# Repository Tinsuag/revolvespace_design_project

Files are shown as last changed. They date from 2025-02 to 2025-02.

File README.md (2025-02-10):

# revolvespace_design_project

## 📡 Introduction

Welcome to the GitHub repository for the **CubeSat SARA solar tracking and Torque Measurement Testing Jig**. This project focuses on the conceptual and functional design of a specialized testing jig developed to measure the torque output of the stepper motor-driven mechanism in SARA, a CubeSat subsystem designed to optimize solar energy intake through precise sun-tracking capabilities.

The testing jig is engineered based on **Advanced Mechanical Design Methods**, ensuring accurate, repeatable, and reliable performance validation. The system simulates real-world load conditions encountered in space while eliminating environmental interferences like temperature fluctuations and gravitational effects.

## 🔑 Key Features
- **🗜️ Modular Rotational Base:** Adaptable to various CubeSat models for versatile testing.
- **⚙️ Torque Measurement System:** Utilizes strain gauges in a Wheatstone bridge configuration, connected to a differential amplifier for precise torque readings.
- **☀️ Sunlight Simulation:** Dual-lamp setup with light sensors to mimic solar intensity variations.
- **🧠 Microcontroller Control:** Arduino Mega for data acquisition and control, with potential upgrades to custom PCBs.
- **🛡️ Safety Protocols:** Integrated overload protection and emergency stop mechanisms.

## 📁 Project Structure
```
/SARA-Torque-Jig
├── Hardware          # Schematics, wiring diagrams, CAD models (SolidWorks files)
├── Firmware          # Arduino code for data acquisition, sensor calibration, motor control
├── Documentation     # Design details, testing protocols, calibration procedures
└── README.md         # Project overview
```

## 🚀 Applications
- Validating the torque performance of SARA’s stepper motor under controlled conditions.
- Simulating space-like environments for CubeSat sun-tracking mechanisms.
- Providing data for performance optimization and reliability improvements.

## 🗂️ Accessing the Code
The Arduino code for controlling the system and processing sensor data is available in the `/Firmware` folder. Detailed instructions for setup, calibration, and operation are provided in the documentation section.

## 🤝 Contributing
This repository is an evolving project aimed at enhancing the performance validation processes for CubeSat mechanisms. **Contributions, suggestions, and collaborations are highly welcome!**

---

**Developed by Tinsae Tesfamichael**

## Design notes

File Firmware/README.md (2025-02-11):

The arduino code is still in progress....

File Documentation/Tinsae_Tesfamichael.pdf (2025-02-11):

TINSAE TESFAMICHAEL | | GitHub (https://github.com/Tinsuag) | Email | LinkedIn (https://www.linkedin.com/in/tinsae-aregahagn/) |

## Conceptual Design of a Testing Jig for Torque Measurements of the SARA

### 1. Introduction

The Sun-Pointing Attitude Regulation Assembly (SARA) is a CubeSat mechanism designed to optimize power intake from solar panels by actively tracking the sun. To ensure its reliability and performance, a testing jig is needed to measure the torque generated by the stepper motor-driven mechanism. This document details the conceptual design of a testing jig based on Advanced Mechanical Design Methods principle.

### 2. Design Requirements & Assumptions

### 2.1 Functional Requirements

- Design a test jig to test the solar tracking performance of SARA and should ensure its modularity to accommodate any type of CubeSat model for testing its tracking performance.
- Measure the torque output of the stepper motor during operation and must cancel any temperature and gravitational interference.
- Ensure accurate data acquisition for performance validation.
- Simulate real-world load conditions encountered in space.
- Provide repeatable and reliable measurements under varying conditions.
- Disruption on advantage and disadvantages.
- Estimation of cost and time needed to implement the jig.

### 2.2 Assumptions

- The test rig is only designed for test purpose not to be included on the CubeSat design structure for launching and the Cube satellite is design on the principles of CubeSat design.
- | The | stepper motor | used in SARA operates at | 5V with a
holding torque of ~0.2 Nm.
- | The | CubeSat structure is 97x97x23 mm | with an estimated
weight of 0.3kg.
- The testing environment is a controlled laboratory setting (20-25°C, minimal vibration).
- | The system will be controlled via an | Arduino-based data
acquisition system [but will be converted to a custom designed PCB if necessary].
- Safety measures such as overload protection and emergency stops are included

### 3. Conceptual Design

### 3.1 Design Overview

The testing jig consists of:

✓ Modular Rotational Base: A stable platform to mount the CubeSat mechanism.
✓ | Torque Sensor (torsional): Captures real-time torque values.
✓ | Stepper Motor & Driver: Provides controlled movement for
testing.
✓ | Light lamp and Sensors: Simulate real sunlight detection.
✓ | Arduino board: Collects and processes torque readings.
✓ | Deferential operational amplifier: to increase the magnitude
of measured voltage.
✓ | Switches to start and stop the operation.
✓ | Load cell with a Wheatstone bridge configuration: o get the
| response electrical voltage according to applied torque by the
| stepper motor.
✓ | Dc power source 12v.
✓ | Two voltage activated relays.

### 3.2 Working principle of the design:

The main controlling microcontroller implemented is an Arduino mega. In order to create the artificial positioning of sun under controlled environment, we used two lamps in a controlled chamber with the light sensor mimicking positional sun intensity variation among each end of the satellite.

Therefore, the variable resistor implemented varies the magnitude of the lamp to reduce meaning the sun is in the direction of the higher energy lamp so the steeper motor rotates reading the potential deference created as it goes through the deferential amplifier. So, the as the stepper motor rotates the intensity of light at both light sensors will balance them out (for this case we are balancing manually to see its response time according to our manipulation).

The applied torque is measured on the principle of torsionmeter in which we place 4 strain gauges onto the shaft in helical position as shown below.

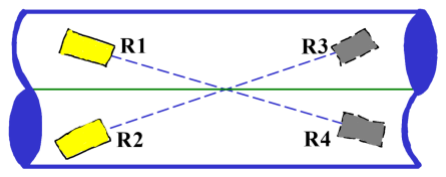
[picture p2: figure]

Figure 1 Strain gauges position on the shaft

The applied torque will deform the shaft in turn deform the strain gauge. Placing those resistors through the Wheatstone bridge will balance both temperature effect but still will give us the residual reading on terminal T1 and T2 as shown in the schematics and it is feed to a deferential amplifier which gives positive or negative voltage output due to the estimation of the torque applied.

Eo =

16(1 + v)KEinT
πD³E
Were, | Eo, the output voltage T, torque applied D, geometry diameter E, young’s modulus of the shaft material Ein, the applied voltage on the Wheatstone bridge. K, strain gauge constant

So, by calibrating the system we can get an instant reading of the torque as we rotate the stepper motor. And this reading can be given through the serial port of the Arduino in the future I will try to incorporate Processing IDE for designing a visual interface to control and monitor instantaneous results.

The system running Arduino code, the Solidworks model assembly and Proteus circuit model is uploaded in my GitHub repository to access it click here. (https://github.com/Tinsuag/revolvespace_design_project.git)

TINSAE TESFAMICHAEL | | GitHub (https://github.com/Tinsuag) | Email | LinkedIn (https://www.linkedin.com/in/tinsae-aregahagn/) |

### 3.3 Sketch/Diagram

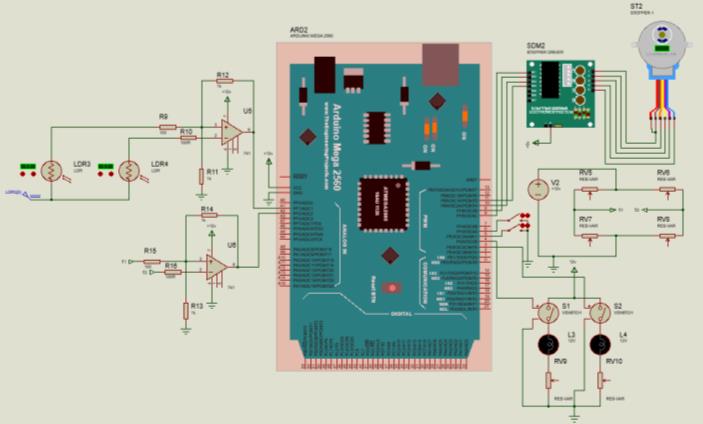
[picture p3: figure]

Figure 2 Schematic diagram of the Jig

### 3.4 Mechanical Assembly

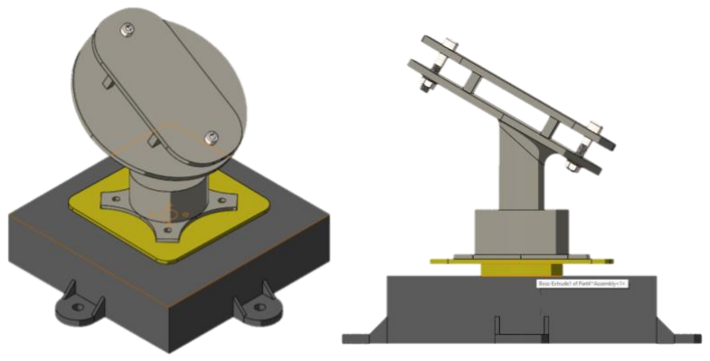
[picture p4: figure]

Figure 3 physical model designed in SolidWorks

As shown the design is aimed to host the CubeSat SARA and rotate following the intensity difference aimed at each light sensor ends of the satellite. The design is made modular in hopes of incorporating the following specifications of the satellite and make is adjustable for any design changes further on the line.

Mechanical specs of SARA
Size: 97X97X23mm
Mass: 0.3kg
Rotation Range: +/ - 180 degrees

ELECTRICAL SPECS
Power supply: | 12V (unregulated 10-18V)
Power consumption: | 5V max
Power transfer type: | flex pcb (twist capsule)

THERMAL SPECS
Operating temperature range: -40/+60 °

### 4. Manufacturing & Assembly Considerations

- Material Selection: Lightweight ABS frame for minimal interference. Produced either by FDM or SLA additive manufacturing process due to its light weight and rigid mechanical property.
- Modularity and calibration: Components should be easily replaceable for testing iterations and easily calibrated in hopes of getting linearity in the torque reading.
- Precision: High-resolution torque measurement for accurate data implementing amplification to clearly detect and evaluate its magnitude.

### 5. Testing & Validation Plan

Step 1: Assembly and System Calibration (zeroing the sensor readings)
Step 2: Controlled torque application with different values of the light sensor readings
Step 3: Data acquisition and analysis
Step 4: Repeatability and error analysis

### 6. Cost & Time Estimation

### 6.1 Cost Breakdown

Component | Unit price (€) | Quantity & Unit | Total
Arduino mega | 52 | 1 | Pcs | 52
Stepper motor – [NEMA – 17] | 12 | 1 | Pcs | 12
Stepper motor driver - [L298N] | 7 | 1 | Pcs | 7
Operational Amplifier | 10 [4pcs] | 2 | Pcs | 10
Strain gauge resistors - [BF350] | 11 [10 pcs] | 4 | Pcs | 11
Lamp | 6 [3pcs] | 2 | Pcs | 6
Light sensor [light dependent resistors] | 9 | 2 | Pcs | 9
Normal Resistors | 7 [100pcs] | 8 | Pcs | 7
Potentiometer – [pot] | 2 | 2 | Pcs | 4
Switches | 1 | 2 | Pcs | 4
ABS for 3D printing | 18 | 1.5 | kg | 27
Relays | 8 | 2 | Pcs | 16
Thrust bearing | 12 | 1 | Pcs | 15
Cupper plate and brush | 10 | 2 | Pcs | 20
Miscellaneous | 50 | | | 50
Total Estimation Cost | | | | 250

### 6.2 Time Estimate

Inquiry Progress | Time requirement
Concept Development | 1 week
Procurement, Prototyping and assembly | 2 weeks
Testing and iteration | 1 week
Final validation | 0.5 week
Total | 4.5 weeks (almost a month)

### 7. Conclusion

Firstly, I want to give thanks for giving me this opportunity to deliver my skills.

The system is designed and run on Arduino microcontroller to give an instant reply for any change in intensity of light source to get the best to generate power for the satellite. Following the change the motor rotates creating a torque on the shaft which is being read by a strain gauge put in the shaft. This creates a change in voltage across the Wheatstone bridge which then gets amplified and be read.

This reading is posted through the serial port of the Arduino and for further advancement can be done by employing a GUI through
processing | IDE | for | better | visualization | and | control.

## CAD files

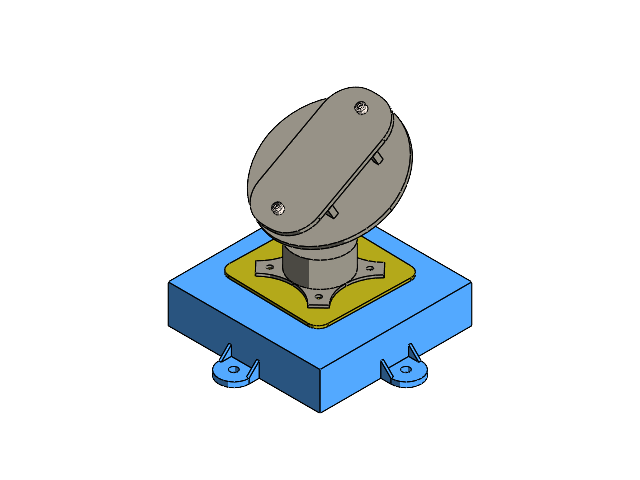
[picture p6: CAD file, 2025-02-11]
Hardware/Assembly.SLDASM
Stepper
Part1^Assembly
Part2^Assembly
flat head screw_am x 4
thrust ball bearing_68_iso
Part3^Assembly
Part4^Assembly
Part5^Assembly
Part6^Assembly
socket head cap screw_iso x 2
hex flange nut gradea_iso x 2

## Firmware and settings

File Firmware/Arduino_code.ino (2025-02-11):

#include <Stepper.h>

const int stepsPerRevolution = 200;  // change this to fit the number of steps per revolution for your motor

// initialize the stepper library on pins 8 through 11:
Stepper myStepper(stepsPerRevolution, 8, 10, 9, 11);

int analogInputPin = A0;       // select the analog input pin for the potentiometer
int potValue = 0;              // variable to store the potentiometer value
int lastPotValue = -1;         // variable to store the previous potentiometer value

const int buttonForward = 2;   // button for forward direction control
const int buttonReverse = 3;  // button for backward direction control

bool isForward = true;         // variable to track the motor direction
bool lastDirection = true;     // variable to store the previous motor direction

void setup() {
  // initialize the serial port:
  Serial.begin(9600);

  // set up buttons as inputs with internal pull-up resistors:
  pinMode(buttonForward, INPUT_PULLUP);
  pinMode(buttonReverse, INPUT_PULLUP);
}

void loop() {
  // read the analog value from the potentiometer:
  potValue = analogRead(analogInputPin);

  // map the potentiometer value to the desired speed range:
  int motorSpeed = map(potValue, 0, 1023, -500, 500);

  // set the speed of the stepper motor:
  myStepper.setSpeed(abs(motorSpeed));

  // check the direction buttons:
  bool currentDirectionForward = digitalRead(buttonForward) == LOW;
  bool currentDirectionReverse = digitalRead(buttonReverse) == LOW;

  // determine the direction based on the button state:
  if (currentDirectionForward && !currentDirectionReverse) {
    isForward = true;
  } else if (!currentDirectionForward && currentDirectionReverse) {
    isForward = false;
  }

  // move the stepper motor in the selected direction:
  if (isForward) {
    myStepper.step(1);  // move forward
  } else {
    myStepper.step(-1);  // move backward
  }

  // check if the potentiometer value has changed:
  if (potValue != lastPotValue) {
    // Print the potentiometer value and stepper motor speed when the value changes:
    Serial.print("Potentiometer Value: ");
    Serial.println(potValue);
    Serial.print("Stepper Motor Speed: ");
    Serial.println(abs(motorSpeed));

    // Update the last potentiometer value:
    lastPotValue = potValue;
  }

  // check if the motor direction has changed:
  if (isForward != lastDirection) {
    // Print the motor direction status when it changes:
    Serial.print("Direction: ");
    Serial.println(isForward ? "Forward" : "Reverse");

    // Update the last direction value:
    lastDirection = isForward;
  }

  delay(50);  // adjust delay as needed for smoother operation
}
